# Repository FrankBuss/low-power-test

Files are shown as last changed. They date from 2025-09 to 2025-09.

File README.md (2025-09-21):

# Ultra-Low Power Sleep Mode Comparison: ATtiny402 vs PIC10F202

## Project Overview
This project demonstrates and compares the ultra-low power sleep capabilities of two modern microcontrollers - the ATtiny402 and PIC10F202. The test program verifies RAM retention during sleep mode and measures actual power consumption using a capacitor discharge method.

## Test Program Functionality
Both microcontrollers run identical test programs that:
1. **Blink Pattern**: LED blinks N times (0.2s on, 0.2s off), followed by 0.5s pause
2. **Sleep Mode**: Press button to enter ultra-low power sleep
3. **RAM Retention Test**: Wake from sleep increments blink count (N+1 blinks)

This pattern proves that RAM contents are preserved even at nanoamp-level sleep currents.

## Circuit Configuration

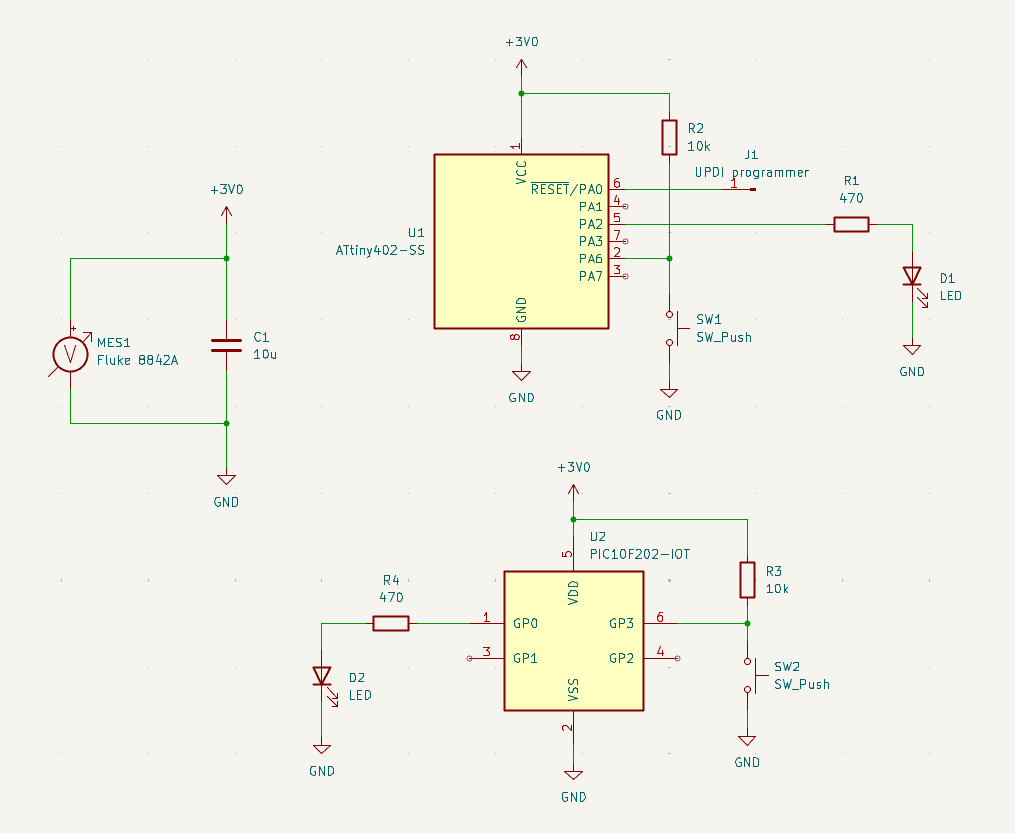
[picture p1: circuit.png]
Test Circuit


### ATtiny402 Circuit (Top)
Recently bought from Farnell, ATTINY402-SSNR, Date code: 2305.

### PIC10F202 Circuit (Bottom)
Recently bought from Farnell, PIC10F202T-I/OT, Date code: 2336.

### Capacitor
10 µF, 0805 SMD, Digikey 1276-6456-1-ND, measured: 9.1 µF.

## Test method
The ATtiny was programmed with avrdude and the serialupdi explained [here](https://github.com/SpenceKonde/AVR-Guidance/blob/master/UPDI/jtag2updi.md). After programming, the FTDI adapter was removed.

The 6 pin PIC was soldered to an adapter board for the 8 pin version, and programmed with a MiniPro TL866CS outside of the circuit, and then the adapter board inserted in a breadboard.

For both tests, the following sequence was done:

- connect 3 V from a power supply, the counter was then 1, LED blinks
- the button was pressed, which put it in sleep mode
- pressed again, the counter was 2 and the LED blinks twice in a loop
- button pressed again for sleep mode
- power supply was disconnected
- time measured until voltage reached 2.5 V with the 20 V range of the Fluke 8842A (> 10 gigohm input resistance, measured about 0.65 µF input capacitance)
- connected power supply again
- button pressed to wake it up
- verify that the counter value was retained and now increased to 3 for the LED blink sequence

The Fluke was connected all the time during the tests. To avoid any influence of it, I removed everything completely from the breadboard as well, and measured it again after 10 minutes for the PIC, which resulted in 6 nA instead of 1.6 nA. Probably influenced by the cable or multimeter.

## Power Consumption Results

For the ATtiny402, 185 nA sleep current was measured, and for the PIC10F202, 1.6 nA, but with the Fluke connected.

## Capacitor Discharge Measurement Method

### Theory
When a capacitor powers a circuit, it discharges according to the fundamental equation:

$$I = C \cdot \frac{dV}{dt}$$

Where:
- $I$ = Current (Ampere)
- $C$ = Capacitance (Farad)
- $dV$ = Voltage change (Volt)
- $dt$ = Time interval (seconds)

### ATtiny402 Measurement with 10 µF Capacitor

- **Voltage drop**: 3.0V → 2.5V (ΔV = 0.5V)
- **Time**: 27 seconds
- **Calculation**:
  $$I = 10 \times 10^{-6} \cdot \frac{0.5}{27} = 185.2 \text{ nA}$$

**Result: 185 nA (0.185 µA)** - Within datasheet limits, typical 100 nA.

With a uCurrent in the 1 mV/nA setting: 148 nA.

### PIC10F202 Measurement with 10 µF Capacitor

Test setup for the PIC with the adapter:

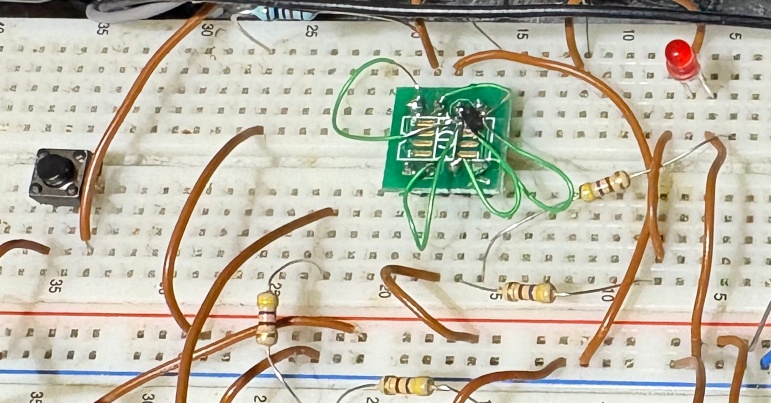
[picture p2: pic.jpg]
PIC Test Setup


- **Voltage drop**: 3.0V → 2.5V (ΔV = 0.5V)
- **Time**: 52 minutes (3,120 seconds)
- **Calculation**:
  $$I = 10 \times 10^{-6} \cdot \frac{0.5}{3120} = 1.60 \text{ nA}$$

**Result: 1.6 nA, but without the Fluke: 6 nA** - Still way below datasheet limits, typical 100 nA at 2 V.

I compared it then with a uCurrent in the 1 mV/nA setting, and could measure 7 nA.

## Software

### Project Structure
The test programs are organized in two MPLAB X projects:
- **ATtiny402**: `attiny402-test.X/`
  - Source: [`main.c`](attiny402-test.X/main.c)
  - Hex file: [`attiny402-test.X.production.hex`](attiny402-test.X/dist/default/production/attiny402-test.X.production.hex)
- **PIC10F202**: `pic10f202-test.X/`
  - Source: [`main.c`](pic10f202-test.X/main.c)
  - Hex file: [`pic10f202-test.X.production.hex`](pic10f202-test.X/dist/default/production/pic10f202-test.X.production.hex)

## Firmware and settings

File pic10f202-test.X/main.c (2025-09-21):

// Simple test program for testing sleep mode current with data retention.
// blinks the LED in a loop x times with 0.2 s delay, then 0.5 s delay,
// and then starts again. After button push, goes to sleep.
// Another button push wakes up and increments x, then blinks the LED etc.

// PIC10F202 version - assumes 4MHz internal oscillator
// GP0 = LED output
// GP3 = Button input with external pull-up (GP3 is input only)

#define _XTAL_FREQ 4000000   // 4MHz internal oscillator
#include <xc.h>

// Configuration bits
#pragma config WDTE = OFF    // Watchdog Timer disabled
#pragma config CP = OFF      // Code protection off
#pragma config MCLRE = OFF   // GP3/MCLR pin function is GP3

// Global variable to test RAM retention across sleep
// 'persistent' prevents C startup code from clearing it on reset/wake
__persistent uint32_t blink_count;

void main(void) {
    // Configure I/O for lowest power consumption
    TRIS = 0b00001000;  // GP3 input (button), GP0,1,2 outputs
    GPIO = 0;            // All outputs low initially (including unused GP1, GP2)

    // Check if we're waking from sleep (STATUS bit 7 = GPWUF)
    if (STATUSbits.GPWUF) {
        // We woke from sleep - increment counter
        blink_count++;

        // Wait for button to be pressed (it triggered the wake)
        while (GP3);    // Wait while button not pressed
        __delay_ms(50); // debounce

        // Wait for button release
        while (!GP3);   // Wait for release
        __delay_ms(50); // debounce
    } else {
        // Normal reset (power-on or MCLR) - initialize counter
        blink_count = 1;
    }

    // Configure OPTION register - no wake-on-change yet
    OPTION = 0b11000000; // Bit 7=1 (GPWU disabled), Bit 6=1 (GPPU disabled)

    while (1) {
        // Blink pattern: blink N times (0.2s on, 0.2s off), then 0.5s pause
        for (uint32_t i = 0; i < blink_count; i++) {
            GP0 = 1;  // LED on

            // Check button during LED on phase (200ms in 10ms chunks)
            for (unsigned char j = 0; j < 20; j++) {
                __delay_ms(10);
                if (!GP3) goto button_pressed;  // GP3 low = button pressed
            }

            GP0 = 0;  // LED off

            // Check button during LED off phase (200ms in 10ms chunks)
            for (unsigned char j = 0; j < 20; j++) {
                __delay_ms(10);
                if (!GP3) goto button_pressed;
            }
        }

        // 0.5 second pause after blink sequence
        for (unsigned char j = 0; j < 50; j++) {
            __delay_ms(10);
            if (!GP3) goto button_pressed;
        }
        continue;

button_pressed:
        // Button was pressed - wait for release
        GP0 = 0;  // Make sure LED is off
        __delay_ms(50);  // 50ms debounce
        while (!GP3);   // Wait for button release
        __delay_ms(50);  // 50ms debounce

        // Enable wake-on-pin-change and enter sleep
        OPTION = 0b01000000; // Bit 7=0 (GPWU enabled)
        SLEEP();            // Enter sleep mode - will RESET on wake!
        NOP();              // Never reached - PIC resets on wake
    }
}

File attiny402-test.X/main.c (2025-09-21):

// Simple test program for testing sleep mode current with data retention.
// blinks the LED in a loop x times with 0.5 s delay, then 1 s delay,
// and then starts again. After button push, goes to sleep.
// Another button push wakes up and increments x, then blinks the LED etc.

// flashed with serialupdi with a FTDI serial port adapter, and a schottky diode:
// https://github.com/SpenceKonde/AVR-Guidance/blob/master/UPDI/jtag2updi.md
// avrdude -c serialupdi -p t402 -P /dev/ttyUSB0 -U flash:w:/home/frank/data/projects/low-power-test/attiny402-test.X/dist/default/production/attiny402-test.X.production.hex:i -F

#define F_CPU 3333333UL // Default internal oscillator is 20MHz/6 = 3.33MHz
#include <avr/io.h>
#include <avr/sleep.h>
#include <avr/interrupt.h>
#include <util/delay.h>

// Global variable to test RAM retention across sleep
uint32_t blink_count = 1;  // Start with 1 blink

ISR(PORTA_PORT_vect){
	PORTA.INTFLAGS = PIN6_bm;  // Clear interrupt flag for PA6
}

int main(void){
	// Disable WDT
	_PROTECTED_WRITE(WDT.CTRLA, 0x00);

	// Set unused pins as INPUT_PULLUP to prevent floating
	PORTA.PIN0CTRL = PORT_PULLUPEN_bm;  // PA0
	PORTA.PIN1CTRL = PORT_PULLUPEN_bm;  // PA1
	PORTA.PIN3CTRL = PORT_PULLUPEN_bm;  // PA3
	PORTA.PIN7CTRL = PORT_PULLUPEN_bm;  // PA7

	// LED on PA2
	PORTA.DIRSET = PIN2_bm;

	// Button on PA6 with external pull-up, interrupt on falling edge
	PORTA.PIN6CTRL = PORT_ISC_FALLING_gc;

	// Configure sleep mode for lowest power
	set_sleep_mode(SLEEP_MODE_PWR_DOWN);
	sei();  // Enable interrupts

	while (1) {
		// Blink pattern: blink N times (0.2s on, 0.2s off), then 0.5s pause
		for (uint32_t i = 0; i < blink_count; i++) {
			PORTA.OUTSET = PIN2_bm;  // LED on

			// Check button during LED on phase (200ms in 10ms chunks)
			for (uint8_t j = 0; j < 20; j++) {
				_delay_ms(10);
				if (!(PORTA.IN & PIN6_bm)) goto button_pressed;
			}

			PORTA.OUTCLR = PIN2_bm;  // LED off

			// Check button during LED off phase (200ms in 10ms chunks)
			for (uint8_t j = 0; j < 20; j++) {
				_delay_ms(10);
				if (!(PORTA.IN & PIN6_bm)) goto button_pressed;
			}
		}

		// 0.5 second pause after blink sequence
		for (uint8_t j = 0; j < 50; j++) {
			_delay_ms(10);
			if (!(PORTA.IN & PIN6_bm)) goto button_pressed;
		}
		continue;

button_pressed:
		// Button was pressed - wait for release
		PORTA.OUTCLR = PIN2_bm;  // Make sure LED is off
		_delay_ms(50);  // Simple debounce
		while (!(PORTA.IN & PIN6_bm));
		_delay_ms(50);

		// Enter sleep
		sleep_enable();
		sleep_cpu();
		sleep_disable();

		// Woken up by button press - increment blink count
		blink_count++;

		// Wait for button release after wake
		_delay_ms(50);
		while (!(PORTA.IN & PIN6_bm));
		_delay_ms(50);
	}
}
